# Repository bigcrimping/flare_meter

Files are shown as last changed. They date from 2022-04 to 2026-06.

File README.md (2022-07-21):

# Xray Flare Meter
An Arduino Nano 33 IoT based gadget which interrogates the latest x-ray flare class information from NOAA GOES Satellite and shows the result visually.

Inspired by a burst of transmission errors picked up in my day job we linked back to a coronal mass ejection I wanted something to show me what the current state of solar flares is.



The data is provided by NOAA in JSON via the website here: https://services.swpc.noaa.gov/json/



The data presented is from the GOES 16 Satellite. 

Using (the excellent) X.27 Stepper motor interface from snafu: https://www.tindie.com/products/boffin/serial-x27-stepper-motor-gauge/

The code is an amalgamation from the following sources

WiFi https://www.arduino.cc/reference/en/libraries/wifinina/wifi.beginap/

SSL https://www.arduino.cc/reference/en/libraries/wifinina/client.connectssl/

JSON Handling https://arduinojson.org/v6/api/json/deserializejson/

## Project Code

The code is here: https://github.com/bigcrimping/flare_meter/tree/main/arduino_code/flare_meter_0.1

You will need to add your WiFi details to the arduino_secrets.h file for the network you wish to connect to.

## Wiring

The wiring is as below, hook up for power/gnd/TX



Inside the chassis it looks like the below



## Mechanical Files



The design comprises (from left to right) a 
Front Plate
Spacer
Back Plate (which mounts the motor)
Chassis
Rear Cover

The needle passes through the spacer to connect to the motor, the Arudino mounts to the Rear Cover with a dab of glue 

The M3 nuts should be a press fit into the mounting holes but may require a dab of super glue.

Fixing required 

10 x M3 nuts

10 x M3x12mm cap head bolts

STLs for printing available here: https://github.com/bigcrimping/flare_meter/tree/main/mechanics

## Dial Artwork

Artwork can be found in PDF format here: https://github.com/bigcrimping/flare_meter/tree/main/dial_artwork



There are a few variations to choose from

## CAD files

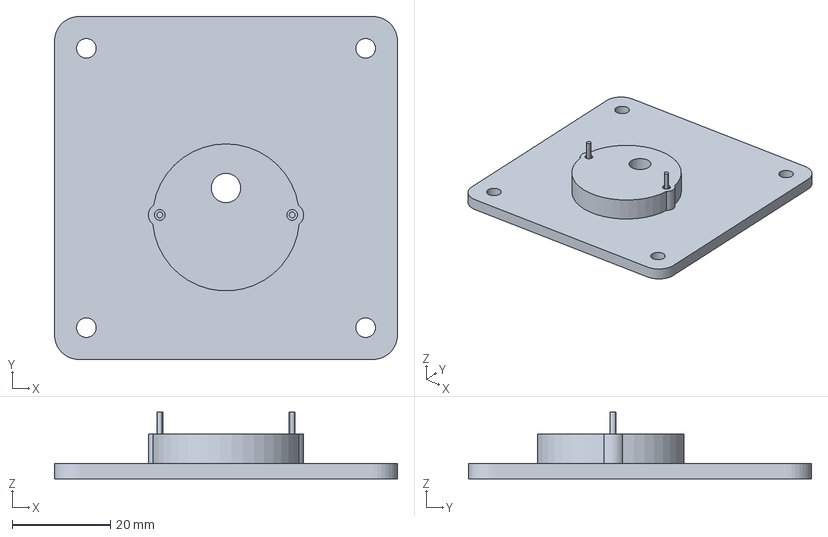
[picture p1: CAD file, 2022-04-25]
mechanics/Back_plate_with_pillar.3MF
70.0 x 70.0 x 13.7 mm

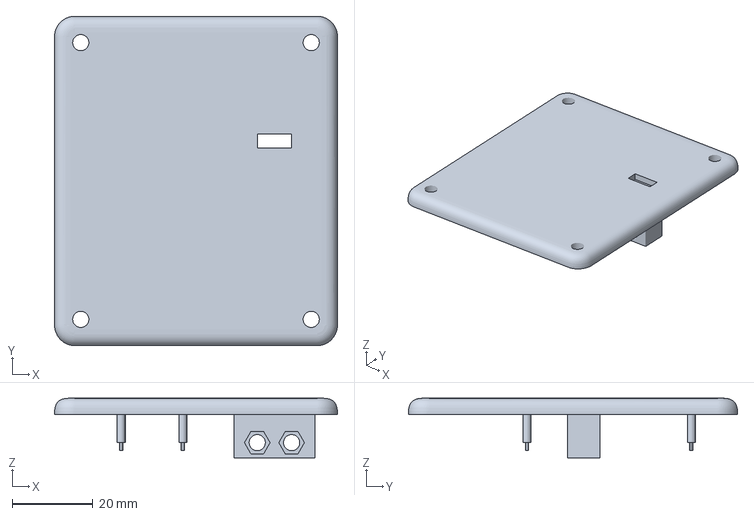
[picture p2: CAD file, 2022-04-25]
mechanics/Rear_cover.3MF
70.0 x 81.5 x 14.8 mm

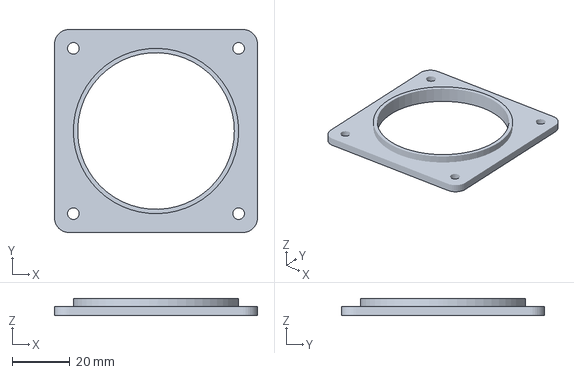
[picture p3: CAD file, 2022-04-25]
mechanics/Front Plate.3MF
70.0 x 70.0 x 6.00 mm

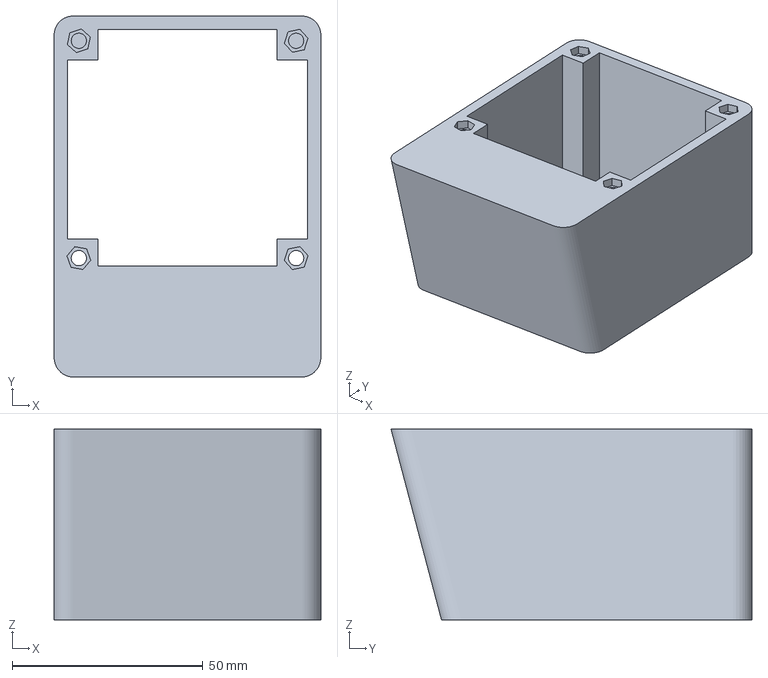
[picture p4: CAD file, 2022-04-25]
mechanics/Chassis.3MF
70.0 x 94.7 x 50.0 mm

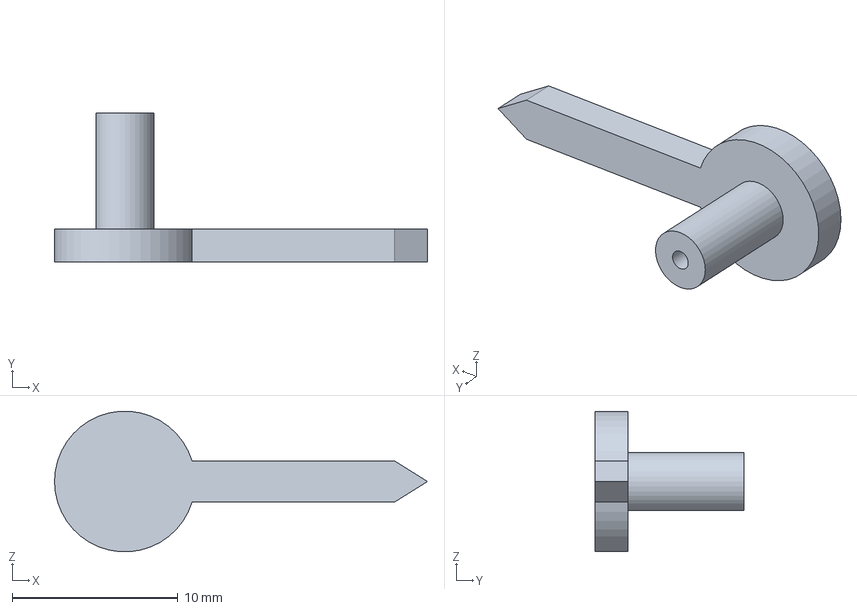
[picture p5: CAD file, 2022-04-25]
mechanics/needle_1.1mm.3MF
22.5 x 9.00 x 8.48 mm

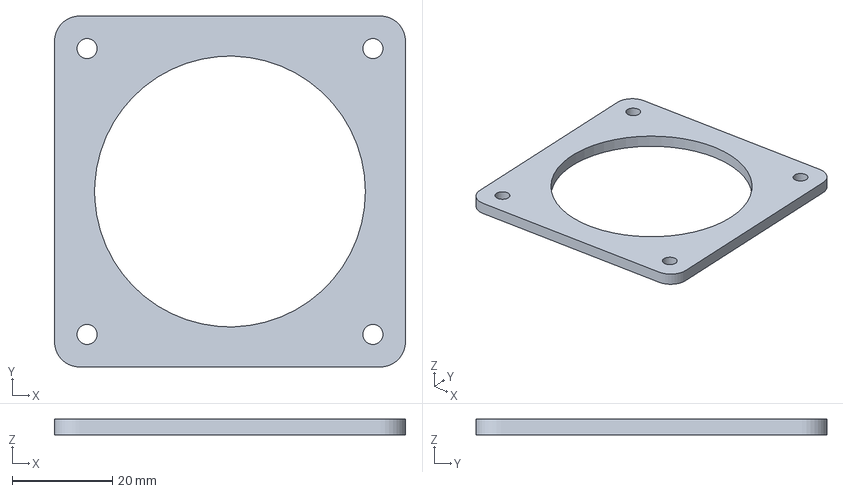
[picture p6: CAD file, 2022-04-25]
mechanics/Spacer.3MF
70.0 x 70.0 x 3.15 mm

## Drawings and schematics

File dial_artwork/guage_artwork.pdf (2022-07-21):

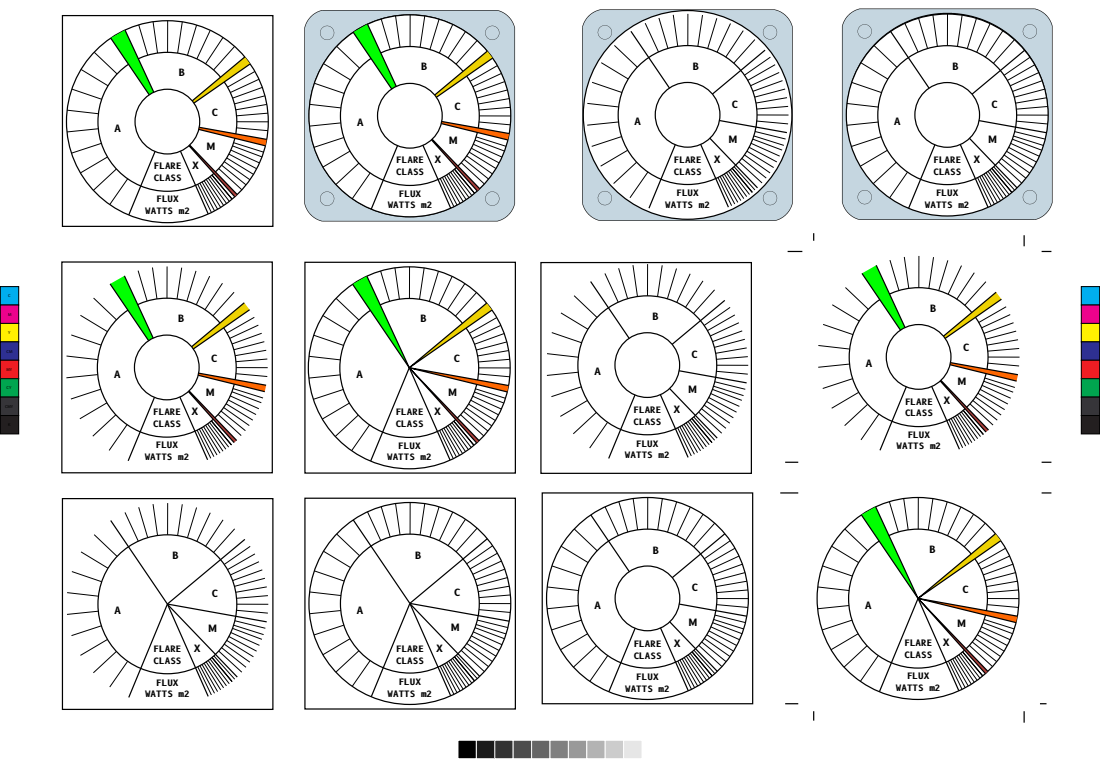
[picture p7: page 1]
FLARE CLASS; FLUX WATTS m; FLARE; CLASS; CMY; CMY K

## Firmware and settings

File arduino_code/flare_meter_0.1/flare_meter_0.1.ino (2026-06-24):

#include <SPI.h>
#include <WiFiNINA.h>
#include <ArduinoJson.h>
#include "arduino_secrets.h"

///////please enter your sensitive data in the Secret tab/arduino_secrets.h
char ssid[] = SECRET_SSID;        // your network SSID (name)
char pass[] = SECRET_PASS;    // your network password (use for WPA, or use as key for WEP)
int status = WL_IDLE_STATUS;     // the Wifi radio's status
char server[] = "services.swpc.noaa.gov";   // NOAA server
String server_results; // Contains the returned JSON string
WiFiSSLClient client;  // Wifi client definition

int dial_value; // Contains the numerical value for the flare
int dial_base;  // Contains the offset for each flare type, A, B, C, M, X
int dial_increment; // Contains the per dial position number for each whole number

StaticJsonDocument<768> doc; // Allocates the memory size of the JSON
     

void setup() {
  Serial.begin(9600); // Start USB Serial Port
  Serial1.begin(2400); // Start comms to meter
  
  // Zero the meter. Sent as the ASCII text "24" (HEX formatting of 0x24),
  // NOT the raw byte 0x24. Confirm which the gauge firmware expects: if it
  // wants the raw byte use Serial1.write(0x24) instead.
  Serial1.println(0x24,HEX); //Zero the meter

  // check for the WiFi module:
  if (WiFi.status() == WL_NO_MODULE) {
    Serial.println("Communication with WiFi module failed!");
    // don't continue
    while (true);
  }

  String fv = WiFi.firmwareVersion();
  if (fv < WIFI_FIRMWARE_LATEST_VERSION) {
    Serial.println("Please upgrade the firmware");

  }

  // attempt to connect to Wifi network:
  connectWiFi();

}

// Connect (or reconnect) to the configured WiFi network, blocking until
// the link is up. Safe to call repeatedly; returns immediately if already
// connected.
void connectWiFi() {
  while (WiFi.status() != WL_CONNECTED) {
    Serial.print("Attempting to connect to WPA SSID: ");
    Serial.println(ssid);
    // Connect to WPA/WPA2 network:
    status = WiFi.begin(ssid, pass);
    // wait 5 seconds for connection:
    delay(5000);
  }
  status = WL_CONNECTED;
}
String connectandgrab(){
  
    String server_result;
    String output;
    // if you get a connection, report back via serial:
    output = client.connectSSL(server, 443);
    
    if (output) {                     //  port 443 for HTTPS
      //Serial.println("connected to server");
      // Make a HTTP request:
      client.println("GET /json/goes/primary/xray-flares-latest.json HTTP/1.1");
      client.println("Host: services.swpc.noaa.gov");
      client.println("Connection: close");
      client.println();
    }
    else
    {
      Serial.println("failed to connect");
      Serial.println(output);
    }
    delay(1000);
  
    // Read the response, skipping the HTTP headers explicitly: everything
    // up to and including the blank line (CRLF CRLF) that terminates them is
    // discarded, and only the body is captured. This is more robust than
    // capturing from the first '{', which could trip on a '{' in a header.
    bool headers_done = false;
    String header_line;
    while (client.available()) {
      char c = client.read();

      if (!headers_done) {
        if (c == '\n') {
          // A line containing only "\r" (or nothing) is the blank line that
          // separates headers from the body.
          if (header_line.length() == 0 || header_line == "\r") {
            headers_done = true;
          }
          header_line = "";
        } else {
          header_line = header_line + c;
        }
      } else {
        server_result = server_result + c;
      }
    }

  // if the server's disconnected, stop the client:
  if (!client.connected()) {
    Serial.println();
    //Serial.println("disconnecting from server.");
    client.stop();
  }

  return server_result;   // always return, even if still connected
}

void loop() {

    // Recover from WiFi dropouts: if the link is down, reconnect before
    // attempting an update. Without this a single AP dropout would stall
    // updates forever.
    if (WiFi.status() != WL_CONNECTED) {
      Serial.println("WiFi connection lost, reconnecting");
      connectWiFi();
    }

    Serial.println("Going into grab routine");
    server_results = connectandgrab();
    Serial.println(server_results);    
    DeserializationError error = deserializeJson(doc, server_results);
    
    if (error) {
      Serial.print(F("deserializeJson() failed: "));
      Serial.println(error.f_str());
      return;
    }
    else {
      String current_class = doc["current_class"];

      // Validate the flare class before mapping. NOAA should return a class
      // letter followed by a numeric magnitude (e.g. "C3"), but an empty,
      // short, or malformed string would otherwise produce a garbage dial
      // value. On bad data, leave the needle where it is and skip this cycle.
      if (current_class.length() < 2 || !isDigit(current_class.charAt(1))) {
        Serial.print("Unexpected current_class format, holding position: ");
        Serial.println(current_class);
        delay(300000);
        return;
      }

      char flare_class = current_class.charAt(0);
      char flare_number = current_class.charAt(1);
      int flare_int = flare_number - '0';
      switch (flare_class) {
        case 'A':
          dial_base = 33;
          dial_increment = 37;
          Serial.println("Switch A");
          break;
        case 'B':
          dial_base = 403;
          dial_increment = 24;
          Serial.println("Switch B");
          break;
        case 'C':
          dial_base = 643;
          dial_increment = 15;
          Serial.println("Switch C");
          break;
        case 'M':
          dial_base = 793;
          dial_increment = 11;
          Serial.println("Switch M");
          break;  
        case 'X':
          dial_base = 903;
          dial_increment = 6;
          Serial.println("Switch X");
          break;  
        default:
          Serial.println("Invalid character inputed to class decoding switch");
          break;
      }

      Serial.println(current_class);
      dial_value = (flare_int*dial_increment) + dial_base;
      Serial1.println(dial_value); 
      
    }
      
    // wait 5 minutes for update:
    delay(300000);
}

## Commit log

2022-04-25 Add mechanical files
    [Back_plate_with_pillar.3MF, Chassis.3MF, Front Plate.3MF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]
2022-04-25 Added Arduino Code
